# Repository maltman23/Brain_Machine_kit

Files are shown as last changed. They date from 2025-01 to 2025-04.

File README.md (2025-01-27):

# Brain Machine Kit  
  
A hackable Sound &amp; Light Machine kit that is easy to make,  
&nbsp;&nbsp;&nbsp;&nbsp;&nbsp;&nbsp;&nbsp;and comes pre-programmed with a really nice 14-minute meditation brainwave sequence.  
Not only that, but you get to hallucinate beautiful colors and patterns along the way...  
  
Great for **learning to solder** -- even for total beginners.  
Great for **hacking on** to play with brainwave sequences.  
Great for **Meditating, Hallucinating, and Tripping Out!**  
  
## The New Brain Machine Kit  
  
  
  
This new version of the Brain Machine kit functions exactly like the other versions.  
It comes pre-programmed with the same really nice meditation sequence.  
The main differences between the new Brain Machine kit and the old one are -- the new one:  
* Has a new PC Board that is much easier to solder together.  
* Uses a small Arduino Nano board, so it is much easier to re-program and hack on.  
* Can be easily re-programmed with other available Brainwave sequences.  
* The Sketch has even more comments in it than the old firmware, making it easy to modify, and great to learn from, if you like.  
* Has the ability to easily add Gama waves to a Brainwave sequence.  
* Has the ability to add alternate blinking LEDs (left/right), instead of both always blinking On/Off simultaneously.
* Runs on one AAA battery, so it is lightweight and more comfortable to wear and use.
* It can easily be re-programmed with new brainwave sequences, such as the Gamma sequence Arduino sketch (included in this repository).  
  
## Meditation sequence  
  
**The Brain Machine comes pre-programmed with a brainwave sequence for a nice 14-minute long Meditation.**  
The sequence starts with lots of Beta (awake / conscious), which is where most people will be when they begin.  
Then Alpha waves (dreamy / trancy) are added, to connect with subconscious Theta that will be coming up.  
Then the Beta is reduced (for less conscious, making it easier to be move more into a trance).  
Then some Theta (more subconscious) is added, and in the middle, there are some pulses of Delta (creativity).  
Then the sequence is reversed, to come back up, nice and refreshed.  
  
The Meditation Arduino sketch is included in this repository.  
  
## Gamma sequence  
  
[Early research over the last few years at MIT](https://picower.mit.edu/news/40-hz-vibrations-reduce-alzheimers-pathology-symptoms-mouse-models) 
and other research labs shows that "plaque" (which is one cause of Alzheimer's pathology) is reduced in mice. 
Studies are ongoing for helping humans with Alzheimer's pathology.  
40 Hz Gamma stimulation may also be [helpful for "chemo brain fog"](https://picower.mit.edu/news/noninvasive-treatment-chemo-brain).  
There may also be some benefit to people with CFS/ME, or people with "brain fog" from long Covid.  
  
A Gamma Arduino sketch is included in this repository.  It plays Gamma waves (40.0 Hz) for one hour.  
    
## Brief History of the Project  
  
The Brain Machine was originally a project I created by hacking the Adafruit MiniPOV3 kit, 
which was a really cool kit, but is no longer available.  
https://www.adafruit.com/product/20  
  
  
This was in 2007, before Arduino was popular, and I used the MiniPOV3 kit as a platform for many interesting projects.  
I used these intriguing projects to make it fun and easy to teach total beginners of all ages how to solder at my workshops all over the world.  

The Brain Machine was one of these projects -- and it was popular.  
  
I wrote up the project for MAKE Magazine, issue #10, in 2007:  
https://makezine.com/article/home/fun-games/the-brain-machine/  
  
  
After giving countless well-attended soldering workshops where Brain Machines, with the MiniPOV3 hack, 
were very popular amongst participants, 
in 2010 I got together with **Limor Fried ("Ladyada")** (who founded Adafruit Industries), to create a Brain Machine kit.  
This kit was popular for quite a number of years.  Although it is no longer available, the cool webpage for it is still up:  
https://www.adafruit.com/product/287  
  
  
In 2011, after Arduino became quite popular for making it much easier to make just about anything with microcontrollers, 
**Chris Sparnicht ("Laughter On Water")**, created an Arduino version of the Brain Machine, based on my original project.  
https://github.com/LaughterOnWater/Arduino-Brain-Machine  
Many thanks, Chris!  
  
**This year (2025) I decided to create a new, much easier to make version of the kit I made with Limor.**  
**The result is the project in this GitHub repository, with all documentation given.**  
  
## More Background of the Brain Machine  
  
It has been known since people started recording brainwaves (with an EEG) in the 1920s, that if you blink lights at brainwave frequencies, when a person watches the blinking lights (with their eyes closed), for most people, their brain will synchronize to the external brainwave frequencies.  (This is called "entrainment".)  And people subjectively say that they feel similarly as if their brain were generating those brainwave frequency on their own (for instance: a state of meditation).  One interesting (and popular) side effect is that people hallucinate beautiful colors and patterns while enjoying the state they are in.  
  
People started creating devices to generate brainwave frequencies as early as the 1950s.  Here is one example -- Brion Gysin's Dreammachine:  
https://en.wikipedia.org/wiki/Dreamachine  
  
  
Later people added sound, in the form of **"binaural beats"**.  
When there are two different pitches generated in a physical space, the difference in frequency between two pitches causes a physical "beat frequency" which everyone can hear.  
If instead, the two different pitches are presented separately to each ear, 
the difference in the two pitches is (oddly) perceived inside most peoples' brains 
as an imaginary beat frequency, which is called a "binaural beat".  
  
In the 1970s, when microcontrollers started to become affordable, people started making commercial devices that created a sequence of brainwave frequencies, presented with blinking lights (in front of glasses) and binaural beats (with headphones). These devices were called **"Sound & Light Machines".**  They were somewhat popular for some people, but also kind of expensive -- several hundred US dollars.  
  
In the early 1990s I created my own Sound & Light Machine, using an inexpensive microcontroller that was available. 
I have been meditating since I was 13 years old, and it became an important part of my well-being and my life. 
I was at a university where I volunteered as a subject for brainwave studies. 
While there I learned that you can record brainwaves and watch as people go into and out of a meditative state (and other states, such as sleep). 
I thought it would be cool to make a device that played those frequencies back 
through LEDs and binaural beats through headphones -- 
using a sequence of brainwave frequencies that were recorded from me going into and out of a nice 15-minute meditation.  The total cost was about US $5. 
I thought that others would like to be able to easily meditate by wearing and using my Sound & Light Machine 
-- especially if I promised them that they would hallucinate beautiful colors and patterns along the way. 
I considered manufacturing and selling them.  But, I was too busy at the time.  
  
Then, over 10 years later, after the first Maker Faire in 2006, after meeting Limor Fried, and seeing her MiniPOV3 kit, 
I thought it would be fun to use her kit as a platform to make it easy for total beginners to learn soldering, 
and to make several projects that I developed using the MiniPOV3 kit -- including what I now called the "Brain Machine".
  
As stated earlier, this turned into the Brain Machine kit that I created with Limor.  It also inspired Chris "Laughter On Water" to make his Arduino version.  And, many years later, I'm now making a new, Arduino-based Brain Machine kit.  
  
## How the Binaural Beats are Generated  

To create the binaural beat frequencies that we desire, 
we choose a central pitch, and generate pitches for each ear, as needed (using the Arduino Tone library), 
which are half of the desired difference higher and lower from the central pitch. 
If we choose a central pitch of 200 Hz, 
we can generate the following pitches for each ear 
to create the desired binaural beat for our brains to synch up with (entrain to):  
|Brainwave type | R Ear  | L Ear  | Beat |  
| :---: | --- | --- | ---: |
| Gama: |  80.00 | 120.00 | 40.0 Hz  |
| Beta: |  92.80 | 107.20 | 14.4 Hz  |
| Alpha: |  94.45 | 105.55 | 11.1 Hz  |
| Theta: |  97.00 | 103.00 |  6.0 Hz  |
| Delta: |  98.90 | 101.10 |  2.2 Hz  |
  
## The Arduino Nano SuperMicro  
  
  
  
For this new version of the Brain Machine kit, I use the Arduino Nano SuperMicro as the controller.  
It is a little bigger than a postage stamp, and is a complete Arduino Nano.  
It also comes with 3 NeoPixel LEDs connected to Arduino Pin 2 (so to use Arduino Pin 2 you would need to unsolder the first NeoPixel).  
It's a nice little board, available on Aliexpress:  
https://www.aliexpress.com/item/1005006468917096.html  
For people interested in playing with this nice little board, I created a Blink_Test program to blink all of the LEDs on this board, as well as document how to easily use it with the free Arduino software:  
https://github.com/maltman23/ArduinoNanoSuperMini  
  
## DISCLAIMER  
  
Light and Sound Machines, such as this one, can be fun for many of us, 
but may be seriously dangerous for those prone to seizures or who are photosensitive. 
When in doubt, seek medical attention. 
You assume all liability for any damage 
done to your equipment, or to your own health, or to those whom you expose to this 
technology. Any and all notes, sketches or associated files within this repository are presented as is, with no promise or gurarantee of any particular result(s).  
  
USE AT YOUR OWN RISK.  
  
## License  
  
Creative Commons Attribution-Sharealike 4.0 International  
CC BY-SA 4.0  
  
https://creativecommons.org/licenses/by-sa/4.0/

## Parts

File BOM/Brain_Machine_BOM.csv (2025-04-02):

Qty | Designator | Description | url | option to choose
1 | B1 | 1xAAA battery holder, PCB, through-hole | https://www.aliexpress.com/item/1005006156901202.html | --
2 | C1, C2 | 1uF, 50V, monolithic ceramic capacitor 50V, 5mm lead spacing | https://www.aliexpress.com/item/1005006779043359.html | 1UF
1 | J1 | 3.5mm Stereo Jack Socket Audio Jack, switched, PJ-307 | https://www.aliexpress.com/item/1005005796606716.html | Pink
2 | LED1, LED2 | 1206 Micro SMD 3V Led Light Wired 30CM | https://www.aliexpress.com/item/1005005180782404.html | 1206 white
1 | MOD1 | 0.9-5V To 5V DC-DC Step-Up Power Module Boost Converter | https://www.aliexpress.com/item/1005003932299815.html | 5V
1 | MOD2 | NANO V3.0 / Nano SuperMini Type-C, ATmega328P, CH340 Serial Port | https://www.aliexpress.com/item/1005006468917096.html | --
2 | R1, R2 | 4.7K, 1/4W, 5%, ammo pack | https://www.aliexpress.com/item/1005002369580841.html | 4.7K
2 | R3, R4 | 47, 1/4W, 5%, ammo pack | https://www.aliexpress.com/item/1005002369580841.html | 47R
1 | S1 | SPST slide switch, 5-pin (On/Off) | https://www.aliexpress.com/item/1005007585395420.html | 25pcs SS12F44 3mm
1 | PCB | PCB | https://pcbway.com
27 | header pins | Male Header Pins, Straight Single Row 40 Pin 0.1 Inch | https://www.aliexpress.com/item/1005007321227560.html | --
1 | safety glasses | Cycling Sunglasses UV Protection Windproof Glasses | https://www.aliexpress.com/item/1005007594480877.html | black
2 | zip ties | 1.8x100mm zip wrap, nylon, black | https://www.aliexpress.com/item/1005001444739470.html | 1.8x100(black)
1 | small bag | 6x9cm ziplock plastic bag | https://www.aliexpress.com/item/1005008239410451.html | 6x9cm(100pcs)
1 | large bag | 12x18cm ziplock plastic bag | https://www.aliexpress.com/item/1005008239410451.html | 12x18cm(100pcs)
1 | headphone | Headphones with stereo 3.5mm jack | https://www.amazon.com/gp/product/B08BT7KH9G
1 | AAA battery | AAA Alkaline battery
1 | graphix | Trippy graphix for front of glasses | https://github.com/maltman23/Brain_Machine_kit/blob/main/Graphix/Graphix_with_Glasses_Outline_Sheet.pdf

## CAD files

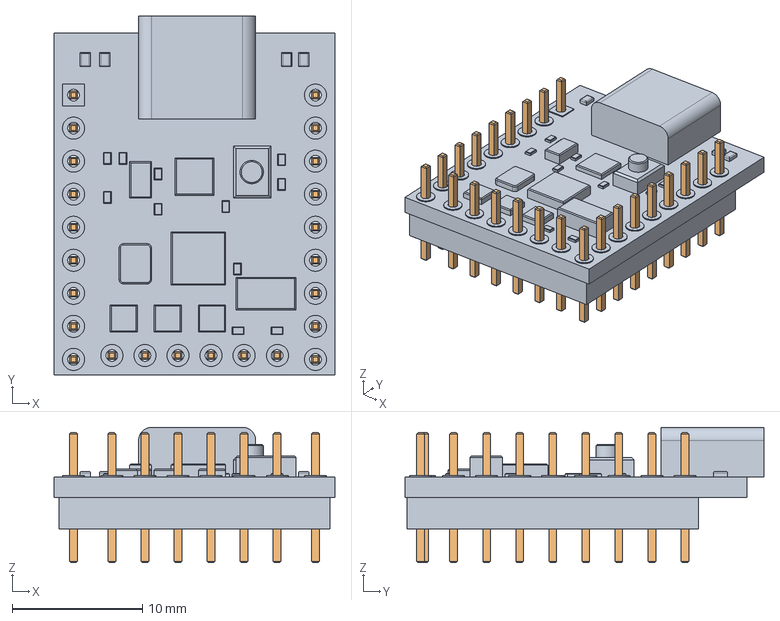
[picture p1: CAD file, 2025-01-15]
KiCad/Brain_Machine_kit/Brain_Machine_kit/KiCad/3Dmodels_for_this_project/Arduino_Nano_SuperMicro--3DModel.step
21.6 x 27.6 x 10.4 mm
PCB
Pins

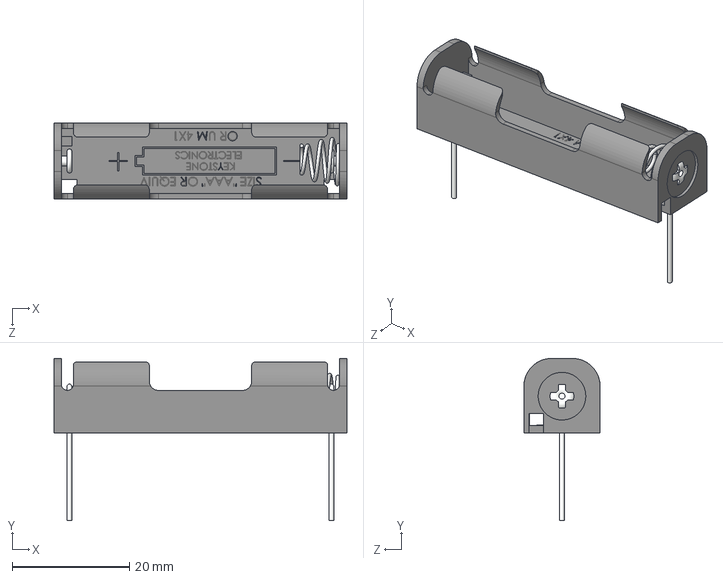
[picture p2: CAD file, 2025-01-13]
KiCad/Brain_Machine_kit/Brain_Machine_kit/KiCad/3Dmodels_for_this_project/Keystone_2466_1xAAA_Battery_Holder_TH.stp
50.0 x 27.7 x 13.0 mm

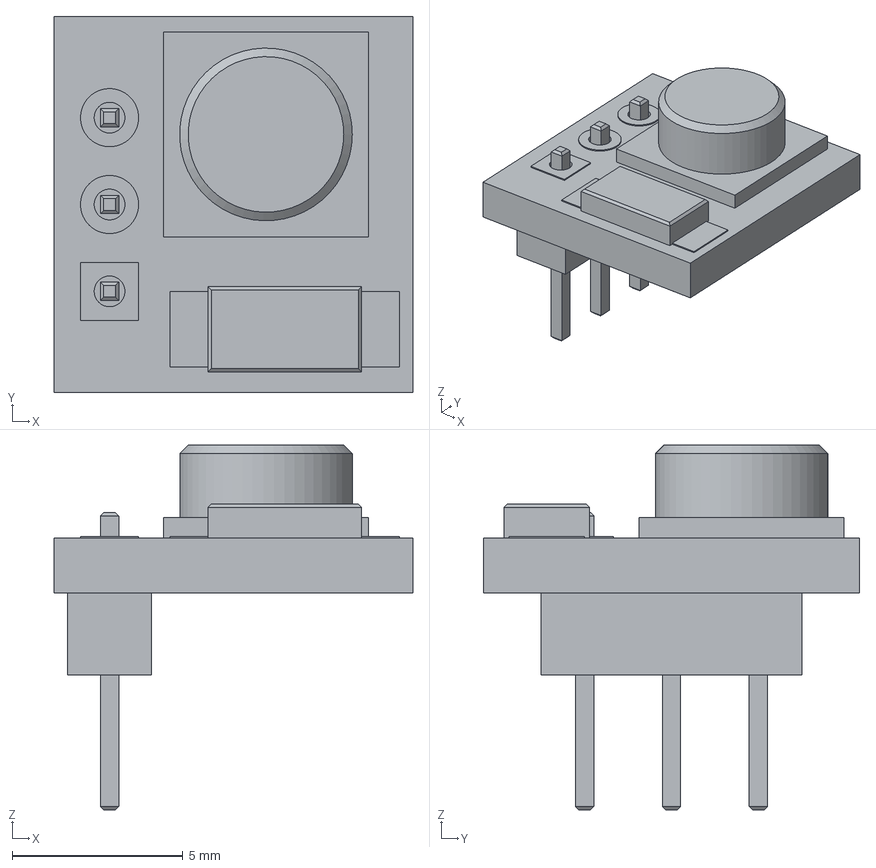
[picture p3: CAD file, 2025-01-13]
KiCad/Brain_Machine_kit/Brain_Machine_kit/KiCad/3Dmodels_for_this_project/0.9-5V_To_5V_DC-DC_Step-Up_Power_Module-Body.step
10.5 x 11.0 x 10.7 mm

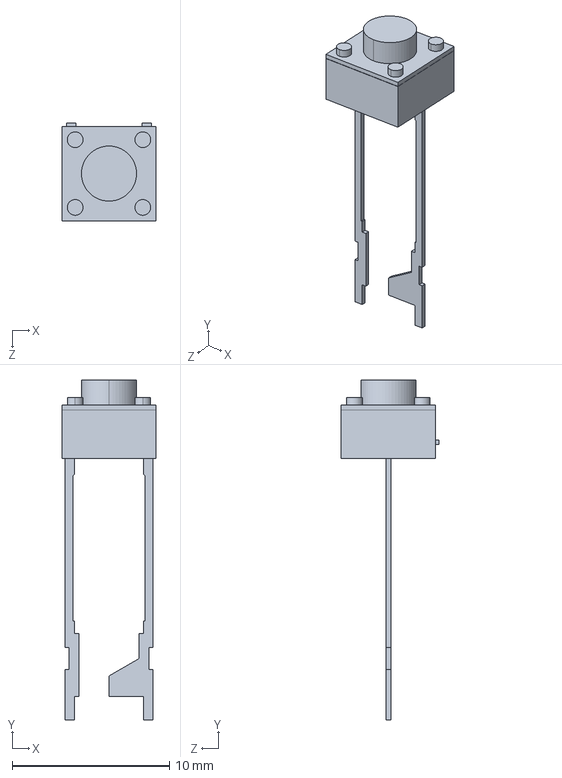
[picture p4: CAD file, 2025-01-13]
KiCad/Brain_Machine_kit/Brain_Machine_kit/KiCad/3Dmodels_for_this_project/Tact_Switch_2-pin--3DModel.step
6.00 x 21.6 x 6.20 mm

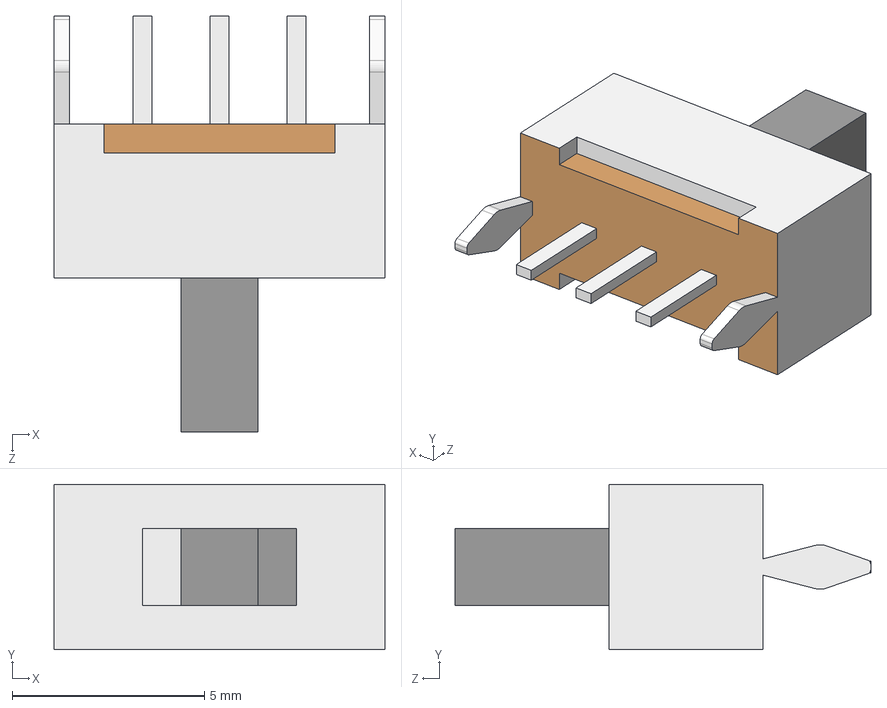
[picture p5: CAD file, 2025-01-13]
KiCad/Brain_Machine_kit/Brain_Machine_kit/KiCad/3Dmodels_for_this_project/SPST_Slide_Switch_5-pin--3DModel.stp
8.60 x 4.30 x 10.8 mm

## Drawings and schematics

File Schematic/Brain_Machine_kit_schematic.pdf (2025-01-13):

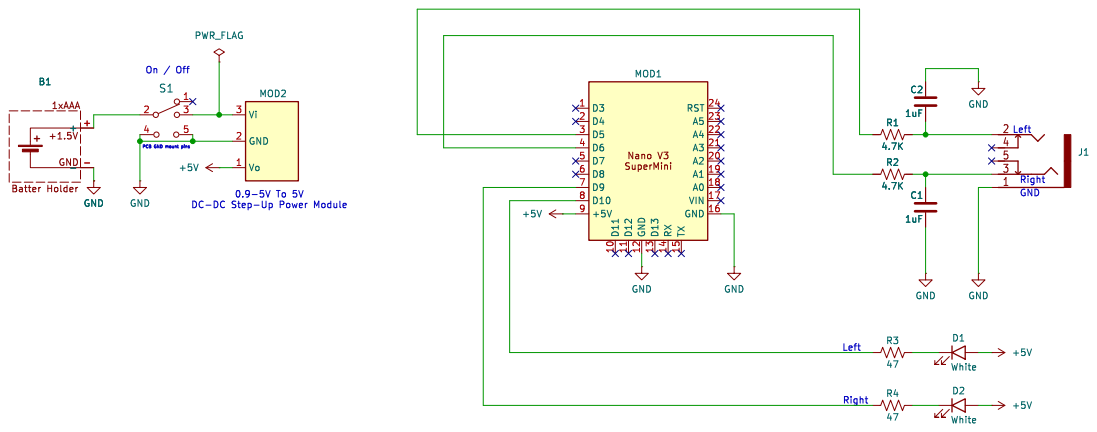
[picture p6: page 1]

Id: 1/1 Title: File: Brain_Machine_kit.kicad_sch Sheet: /

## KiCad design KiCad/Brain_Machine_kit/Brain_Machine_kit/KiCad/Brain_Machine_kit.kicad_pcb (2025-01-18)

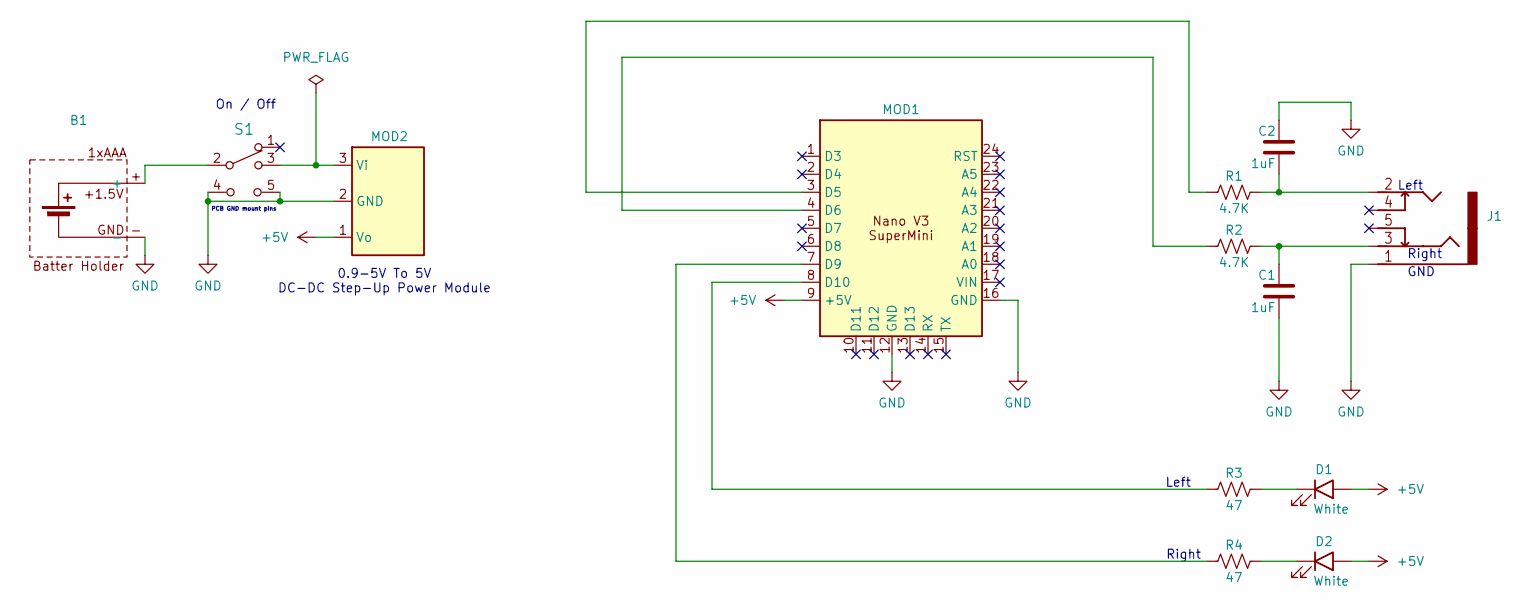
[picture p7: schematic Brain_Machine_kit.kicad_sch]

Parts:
B1: Battery_Holder_Keystone_2466_1xAAA_TH
C1, C2: 1uF; Cap_THT_0.5mm
D1, D2: White; LEDs_with_wires
J1: 3.5mm_CUI_SJ1-3525NG_Horizontal
MOD1: Nano_V3_SuperMini
MOD2: 0.9-5V_To_5V_DC-DC_Step-Up_Power_Module
R1, R2: 4.7K; Resistor_THT_0.25W
R3, R4: 47; Resistor_THT_0.25W
S1: SPST, 5-pin; SPST_Slide_Switch_5-pin

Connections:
+5V: D1.1 (A), D2.1 (A), MOD1.9 (+5V), MOD2.1 (Vo)
GND: B1.-, C1.2, C2.1, J1.1 (GND), MOD1.12 (GND), MOD1.16 (GND), MOD2.2 (GND), S1.4 (GND), S1.5 (GND)
unnamed: B1.+, S1.2
unnamed: D1.2 (K), R3.2
unnamed: D2.2 (K), R4.2
unnamed: C1.1, J1.3 (Ring), R2.2
unnamed: C2.2, J1.2 (Tip), R1.2
unnamed: MOD1.3 (D5), R1.1
unnamed: MOD1.4 (D6), R2.1
unnamed: MOD1.7 (D9), R4.1
unnamed: MOD1.8 (D10), R3.1
unnamed: MOD2.3 (Vi), S1.3

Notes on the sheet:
On / Off
GND
Right
0.9-5V To 5V DC-DC Step-Up Power Module
Left
PCB GND mount pins

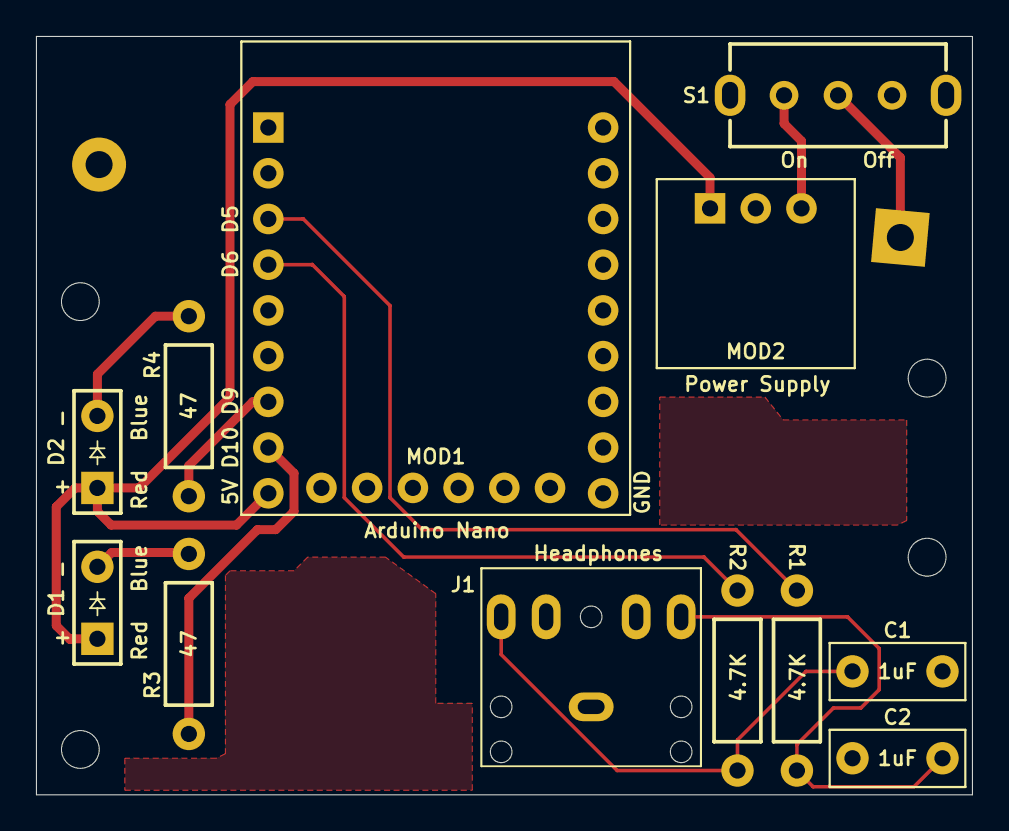
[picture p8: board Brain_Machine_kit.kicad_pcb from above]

Board: 2 copper layers, 52.0 x 42.1 mm, 13 parts (1 on the bottom side), 12 nets.

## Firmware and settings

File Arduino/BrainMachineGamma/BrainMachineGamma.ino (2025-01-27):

/***************************************************
Sketch: Sound & Light Machine for Arduino -- Gamma for 1 hour
Author: Chris Sparnicht - http://low.li
Creation Date: 2011.01.31
Last Modification Date: 2011.02.12
License: Creative Commons 2.5 Attrib. & Share Alike

Modified from Chris Sparnicht's sketch by Mitch Altman
27-Jan-2025

Derivation and Notes:
Chris used a stereo 10K Ohm potentiometer to reduce
the volume of the audio for the ears. 
[Mitch:  I used a fixed 4.7K resistor for each ear, 
 which works well with the earbuds that come with the kit I designed.]

This arduino sketch is based on the original Sound & Light Machine 
by - Mitch Altman - 19-Mar-07 as featured in Make Magazine 10.
https://makezine.com/article/home/fun-games/the-brain-machine/
and then modified for Arduino by Chris Sparnicht.
See notes in code below for how Chris adapted Mitch Altman's version for Arduino.
Mitch then modified Chris' sketch to its present form.

The sleep coding comes partially from here:
http://www.arduino.cc/playground/Learning/ArduinoSleepCode
[Mitch note:  the above link is no longer available, but here is another link with good info for putting an Arduino into low-power modes:
 https://docs.arduino.cc/learn/electronics/low-power/]
***************************************************/


/***************************************************
SOME INFORMATION ABOUT PROGMEM:
First, you have to use #include <avr/pgmspace.h> for table arrays - PROGMEM
The Arduino compiler creates code that will transfer all constants into RAM when the microcontroller
resets.  This hardware could probably hold all this data in memory, but since the original system
used a table (brainwaveTab) that is was too large to transfer into RAM in the original microcontroller,
we're taking the same approach.  This is accomplished by using the library for PROGMEM. 
(This is used below in the definition for the brainwaveTab).  Since the
C compiler assumes that constants are in RAM, rather than in program memory, when accessing
the brainwaveTab, we need to use the pgm_read_byte() and pgm_read_dword() macros, and we need
to use the brainwveTab as an address, i.e., precede it with "&".  For example, to access
brainwaveTab[3].bwType, which is a byte, this is how to do it:
     pgm_read_byte( &brainwaveTab[3].bwType );
And to access brainwaveTab[3].bwDuration, which is a double-word, this is how to do it:
     pgm_read_dword( &brainwaveTab[3].bwDuration );
 ***************************************************/


/***************************************************
LIBRARIES - Define necessary libraries here.
***************************************************/
#include <avr/pgmspace.h> // for arrays - PROGMEM 
#include <Tone.h>         // Include the arduino tone library -- used for generating sound at any desired integer frequency
#include <avr/sleep.h>    // A library to control the sleep mode -- used to put the microcont
#include <avr/power.h>    // A library to control power

/***************************************************
GLOBALS
We use these globals to define the pin numbers.
This makes it easier to change pin numbers later
without needing to search and replace them in many places.
***************************************************/
#define rightEye 9      // Define pinout for right eye
#define leftEye 10      // Define pinout for left eye
#define leftEarLow 5    // Define pinout for right ear
#define rightEarLow 6   // Define pinout for left ear
//#define wakePin 3     // the input pin where the pushbutton is connected.
// [Mitch:  I got rid of the Push-Button on/off switch, 
//  and replaced it with a slide switch for the new Brain Machine kit]


/***************************************************
BRAINWAVE TABLE
See 'Some information about PROGMEM' above.
Table of values for Gamma start with 
a few seconds of delta followed by beta (just to see that the sequence has started)
then play Gamma for 1 hour 
then again play a few seconds of delta followed by beta (just to see that the sequence has ended)
***************************************************/
struct brainwaveElement {
  char bwType;  // 'a' for Alpha, 'b' for Beta, 't' for Theta,'d' for Delta or 'g' for gamma ('0' signifies last entry in table)
// A, B, T, D and G offer alternating flash instead of concurrent flash (which aren't used in the following table, but are available for experiementing)
// {0,0} must be the last element of the Brainwave table -- it signifies the end of the Brainwave table
  unsigned long int bwDuration;  // Duration of each Brainwave element (divide by 10,000 to get seconds)
                                 // For example:
                                 //    { 'b', 600000 }   plays a beta wave for 60 seconds
// The following table adds up to 3612 seconds, which is an hour of Gamma, with a short intro/outro of slower frequencies to be able to see the beginning and end of the sequence).  
} const brainwaveTab[] PROGMEM = { 
{ 'd',   20000 },
{ 'b',   40000 },
{ 'g', 6000000 },
{ 'g', 6000000 },
{ 'g', 6000000 },
{ 'g', 6000000 },
{ 'g', 6000000 },
{ 'g', 6000000 },
{ 'b',   40000 },
{ 'd',   20000 },
{ '0', 0 }
};


/***************************************************
VARIABLES for the Tone generator
We use the Tone libary to generate the desired sounds for the Brain Machine.

When there are two different pitches generated in a physical space 
the difference in Hz between two pitches causes a physical "beat frequency" which everyone can hear. 
When the two different pitches are presented separately to each ear, 
the difference in the two pitches is (oddly) perceived in most peoples' brains 
as an imaginary beat frequency, which is called a "binaural beat".
To create the binaural beat frequencies that we desire, 
we choose a central pitch, and generate pitches for each ear, as needed (using the Tone library),
which are half of the desired difference up and down from the central pitch.
If we choose a central pitch of 100 Hz, 
we can generate the following pitches for each ear 
to create the desired binaural beat for our brains to synch up with
BTW, when a brain synchs up to an external frequency, it is called "entrainment".
For the Brain Machine, we entrain our brains using both sound (ears) and light (eyes).
     Brainwave type      R Ear    L Ear    Beat
            Gamma:        80.00   120.00   40.0 Hz
            Beta:         92.80   107.20   14.4 Hz
            Alpha:        94.45   105.55   11.1 Hz
            Theta:        97.00   103.00    6.0 Hz
            Delta:        98.90   101.10    2.2 Hz

You can use any central pitch you like. 
For meditation and relaxation, 
I think a lower tone between 100 and 220 is easier on the ears.
Others prefer something around 440 (A above Middle C).
Isolating the central pitch makes it easy for
the user to choose a preferred frequency base.

***************************************************/
float binauralBeat[] = { 40.0, 14.4, 11.1, 6.0, 2.2 }; // For gamma, beta, alpha, theta, and delta beat differences.
Tone rightEar;              // For using the Tone library for generating a pitch for the right ear
Tone leftEar;               // For using the Tone library for generating a pitch for the left ear
float centralTone = 100.0;  // We starting at this central frequency and spread the pitches for each ear from there to create the desired beat frequencies.

// Definitions for LED blink timings for the 'blink_LEDs' and 'alt_blink_LEDS' functions
unsigned long int duration = 0;
unsigned long int onTime = 0;
unsigned long int offTime = 0;


/***************************************************
  SETUP initializes our Arduino pins for blinking the LEDs for each eye and sending sound to the speakers for each ear.
  Arduino pins we'll use:
  pin  7  - on/off switch  -- [Mitch:  this switch is no longer used]
  pin  5  - Left ear
  pin  6  - Right ear
  pin  9  - Right eye LED1
  pin 10  - Left eye LED2
  pin 5V  - Power for everything, including the common anode on LED's
  pin GND - Ground for power, LEDs, and speakers
*/
void setup()  { 
  rightEar.begin(rightEarLow);      // Enables the Tone library to play a pitch on the rightEarLow output pin
  leftEar.begin(leftEarLow);        // Enables the Tone library to play a pitch on the leftEarLow output pin
  pinMode(rightEye, OUTPUT);        // Output pin for rightEye LED
  pinMode(leftEye, OUTPUT);         // Output pin for LeftEye LED
  //pinMode(wakePin, INPUT_PULLUP); // Pin input at wakePin  -- [Mitch:  no longer used]

  // The following lines are for using the myTimer() function to empirically determine the value for DelayCount.
  // Display (in the Serial Monitor) the number of milliseconds before playing the Brainwave table (which should be '0'):
  Serial.begin(9600);
  Serial.print("Start");
  myTimer();                        // Print out the time value from the millisec() function
}


/***************************************************
   MAIN LOOP - tells our program what to do.

   It plays each element in the brainwaveTab,
   and then puts the microcontroller into lower-power mode (sleep) to save battery.
***************************************************/

void loop() {
  int j = 0;
  while (pgm_read_byte(&brainwaveTab[j].bwType) != '0') {  // '0' signifies end of table
    do_brainwave_element(j);                               // Play one element of the Brainwave Table
    j++;
  }
 
  // Shut down everything and put the microcontroller to sleep (low-power mode)
  analogWrite(rightEye, 255);  // common anode - HIGH (255) means 'Off'
  analogWrite(leftEye, 255);   // common anode - HIGH (255) means 'Off'
  rightEar.stop();
  leftEar.stop();
  // The following lines are for using the myTimer() function to empirically determine the value for DelayCount.
  // Display (in the Serial Monitor) the number of milliseconds used to reach the end of the Brainwave table:
  Serial.print("End");
  myTimer();                   // Print out the time value from the millisec() function
  delay(500);                  // Give the serial port time to finish displaying the time value before putting the microcontroller to sleep
  sleepNow();                  // Put the microcontroller into sleep mode

  // The microcontroller should never wake up, 
  // since we did not enable any interrupts to do so, 
  // but just in case, we will just loop here till the unit is turned Off with the slide switch.
  Serial.println("Hey!  The microcontroller woke up (even though it shouldn't have!");
  while(1){}
}


/***************************************************
This function delays the specified number of 1/10 milliseconds
***************************************************/

void delay_one_tenth_ms(unsigned long int ms) {
  unsigned long int timer;
  const unsigned long int DelayCount=196;  // This value was determined by trial and error
                                           //   (for more info please see the notes in the myTimer() function at the bottom of this sketch) 
 
  while (ms != 0) {
    // Toggling PD0 is done here to force the compiler to do this loop, rather than optimize it away
    for (timer=0; timer <= DelayCount; timer++) {PIND |= 0b0000001;};
    ms--;
  }
}
 
/***************************************************
This function blinks the LEDs 
(connected to Arduino Pins 9 & 10 - 
for Right eye, Left eye, respectively)
and keeps them blinking for the Duration specified 
(Duration given in 1/10 millisecs).
This function also acts as a delay for the Duration specified.
In this particular instance, digitalWrites are set 
for common anode, so LED "On" = LOW (0) and LED "Off" = HIGH (255).
***************************************************/

// Blink both LEDs (left eye and right eye) On and Off together
void blink_LEDs( unsigned long int duration, unsigned long int onTime, unsigned long int offTime) {
  for (int i=0; i<(duration/(onTime+offTime)); i++) {   
    analogWrite(rightEye, 0);     // common anode - LOW (0) means 'On'
    analogWrite(leftEye, 0);      // common anode - LOW (0) means 'On'
                                  // Both LEDs are now turned On     
    delay_one_tenth_ms(onTime);   //   Keep them On for a duration of onTime     
    
    analogWrite(rightEye, 255);   // common anode - HIGH (255) means 'Off'
    analogWrite(leftEye, 255);    // common anode - HIGH (255) means 'Off'
                                  // Both LEDs are now turned Off
    delay_one_tenth_ms(offTime);  //   Keep them Off for a duration of offTime   
  } 
} 

// NOTE: The Brainwave Table in this sketch does not use alternate blinking LEDs -- this is here for you to experiment with.
// Blink both LEDs (left eye and right eye) in an alternating sense -- one is On when the other is Off
void alt_blink_LEDs( unsigned long int duration, unsigned long int onTime, unsigned long int offTime) {
  for (int i=0; i<(duration/(onTime+offTime)); i++) {   
    analogWrite(rightEye, 0);     // common anode - LOW (0) means 'On'
    analogWrite(leftEye, 255);    // common anode - HIGH (255) means 'Off'
                                  // Both LEDs are appropriately On / Off
    delay_one_tenth_ms(onTime);   //   Keep them in that state for a duration of onTime
    
    analogWrite(rightEye, 255);   // common anode - HIGH (255) means 'Off'
    analogWrite(leftEye, 0);      // common anode - LOW (0) means 'On'
                                  // Both LEDs are appropriately On / Off
    delay_one_tenth_ms(offTime);  //   Keep them in that state for a duration of offTime
  } 
} 


/***************************************************
This function starts with a central audio frequency and
splits the difference between two pitches
to create a binaural beat (between Left and Right ears) 
for a Brainwave Element.
(See notes above for beat creation method.)

The blink_LEDs() function has 3 values:
   duration
   onTime
   offTime
The onTime+offTime are calculated so that the LED blink-rate
is the same as the binaural beat frequency for a given brainwave value.
For example, for "a" or "A" (for Alpha), the binaural beat frequency is 11.1Hz.
To get a blink-rate of as close to 11.1Hz as possible, onTime=451 and offTime=450:
     10,000/(451+450) = 11.0988Hz

For each Brainwave type given below, there are two cases (one with lower-case letter, and one with upper-case letter):
* one with both LEDs blinking the same (lower-case letter, such as 'b')
* one with the LEDs blinking alternately (upper-case letter, such as 'B').
The Brainwave table included near the top of this sketch does not make use of alternating blinking.  They are included here in case you would like to experiment.
***************************************************/

void do_brainwave_element(int index) {     
  char brainChr = pgm_read_byte(&brainwaveTab[index].bwType);     
    
  switch (brainChr) {
    case 'g':
      // Gamma
      // Generate a binaural beat of 40.0Hz
      rightEar.play(centralTone - (binauralBeat[0]/2));
      leftEar.play(centralTone + (binauralBeat[0]/2));  
      // delay for the time specified in the table while blinking the LEDs at 40.0Hz
      blink_LEDs( pgm_read_dword(&brainwaveTab[index].bwDuration), 125, 125 );
      return;   // Gamma
 
    case 'G':
      // Gamma - with alternating blinks
      // Generate a binaural beat of 40.0Hz
      rightEar.play(centralTone - (binauralBeat[0]/2));
      leftEar.play(centralTone + (binauralBeat[0]/2));  
      // delay for the time specified in the table while blinking the LEDs at 40.0Hz
      alt_blink_LEDs( pgm_read_dword(&brainwaveTab[index].bwDuration), 125, 125 );
      return;   // Gamma -- with alternating blinks

    case 'b':         
      // Beta       
      // Generate binaural beat of 14.4Hz       
      rightEar.play(centralTone - (binauralBeat[1]/2));
      leftEar.play(centralTone + (binauralBeat[1]/2));  
      // delay for the time specified in the table while blinking the LEDs at 14.4Hz
      blink_LEDs( pgm_read_dword(&brainwaveTab[index].bwDuration), 347, 347 );
      return;   // Beta
 
    case 'B':         
      // Beta - with alternating blinks
      // Generate binaural beat of 14.4Hz       
      rightEar.play(centralTone - (binauralBeat[1]/2));
      leftEar.play(centralTone + (binauralBeat[1]/2));  
      // delay for the time specified in the table while blinking the LEDs at 14.4Hz
      alt_blink_LEDs( pgm_read_dword(&brainwaveTab[index].bwDuration), 347, 347 );
      return;   // Beta - with alternating blinks
 
    case 'a':
      // Alpha
      // Generate a binaural beat of 11.1Hz
      rightEar.play(centralTone - (binauralBeat[2]/2));
      leftEar.play(centralTone + (binauralBeat[2]/2));  
      // delay for the time specified in the table while blinking the LEDs at 11.1Hz
      blink_LEDs( pgm_read_dword(&brainwaveTab[index].bwDuration), 451, 450 );
      return;   // Alpha
 
    case 'A':
      // Alpha - with alternating blinks
      // Generate a binaural beat of 11.1Hz
      rightEar.play(centralTone - (binauralBeat[2]/2));
      leftEar.play(centralTone + (binauralBeat[2]/2));  
      // delay for the time specified in the table while blinking the LEDs at 11.1Hz
      alt_blink_LEDs( pgm_read_dword(&brainwaveTab[index].bwDuration), 451, 450 );
      return;   // Alpha - with alternating blinks
 
    case 't':
      // Theta
      // Generate a binaural beat of 6.0Hz
      rightEar.play(centralTone - (binauralBeat[3]/2));
      leftEar.play(centralTone + (binauralBeat[3]/2));  
      // delay for the time specified in the table while blinking the LEDs at 6.0Hz
      blink_LEDs( pgm_read_dword(&brainwaveTab[index].bwDuration), 833, 833 );
      return;   // Theta
 
    case 'T':
      // Theta - with alternating blinks
      // Generate a binaural beat of 6.0Hz
      rightEar.play(centralTone - (binauralBeat[3]/2));
      leftEar.play(centralTone + (binauralBeat[3]/2));  
      // delay for the time specified in the table while blinking the LEDs at 6.0Hz
      alt_blink_LEDs( pgm_read_dword(&brainwaveTab[index].bwDuration), 833, 833 );
      return;   // Theta - with alternating blinks
 
    case 'd':
      // Delta
      // Generate a binaural beat of 2.2Hz
      rightEar.play(centralTone - (binauralBeat[4]/2));
      leftEar.play(centralTone + (binauralBeat[4]/2));  
      // delay for the time specified in the table while blinking the LEDs at 2.2Hz
      blink_LEDs( pgm_read_dword(&brainwaveTab[index].bwDuration), 2253, 2253 );
      return;   // Delta
 
    case 'D':
      // Delta - with alternating blinks
      // Generate a binaural beat of 2.2Hz
      rightEar.play(centralTone - (binauralBeat[4]/2));
      leftEar.play(centralTone + (binauralBeat[4]/2));  
      // delay for the time specified in the table while blinking the LEDs at 2.2Hz
      alt_blink_LEDs( pgm_read_dword(&brainwaveTab[index].bwDuration), 2272, 2273 );
      return;   // Delta - with alternating blinks
 
    // this should never be executed, since we catch the end of table in the main loop
    default:
      return;      // end of table
  }
}


/***************************************************
SLEEP function
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

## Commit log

2025-01-13 Create BrainMachine.ino
    Add Arduino sketch for the Brain Machine kit
2025-01-13 Add KiCad files
    Add KiCad source files for Brain Machine kit
    [0.9-5V_To_5V_DC-DC_Step-Up_Power_Module-Body.step, Brain_Machine_kit.kicad_pcb, Brain_Machine_kit.kicad_sch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]
2025-01-13 add BOM and Schematic diagram
    Add BOM and Schematic diagram for Brain Machine kit
    [Brain_Machine_BOM.csv]
2025-01-15 Create Arduino_Nano_SuperMicro--3DModel.step
    Added 3D model from Arduino Nano SuperMicro board
    [Arduino_Nano_SuperMicro--3DModel.step]
2025-01-16 Update README.md
    Added link to Chris Sparnicht's Github repository (LaughterOnWater) for his Arduino Brain Machine.
2025-01-18 update Arduino Nano 3D model on PCB
    update Arduino Nano 3D model on PCB
    [Brain_Machine_kit.kicad_pcb]
2025-01-27 Add Graphix, Gerbers, Test Video
    Add Graphix, Gerbers, Test Video
2025-01-27 Update Brain_Machine_BOM.csv
    Updated BOM, including link to trippy graphix
    [Brain_Machine_BOM.csv]
2025-01-27 Update README.md
    Change central frequency for binaural beat generation to 100.0 Hz (instead of 200.0 Hz).
2025-01-27 Update README.md
    Add sections for the Meditation brainwave sequence Arduino sketch and for the Gamma brainwave sequence Arduino sketch.
2025-01-28 Create BrainMachineAssembly.pdf
    Added Assembly Instructions
2025-04-02 Update Brain_Machine_BOM.csv
    fix errors in quantities of some items
    [Brain_Machine_BOM.csv]
